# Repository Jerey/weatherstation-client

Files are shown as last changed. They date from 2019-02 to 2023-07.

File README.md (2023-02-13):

# Weatherstation - Client

## Idea

The idea was to create a platform tracking various climate data, which can be extended and has no dependencies to the visualization. Therefore a network based solution was chosen.
<sup>[1](#EnergyConsumption)</sup>

As basis for the project a D1-mini was chosen, as it comes with onboard WiFi. But also other platforms can be used (e.g.: NodeMCU, ...).

The idea is to read the sensor data and send it via MQTT. Anyone who wants to use the data, can simply subscribe to the topic `/esp/#`. To indicate the type of data, the messages are defined by a MAC (to know from which client the message comes from), the type of data and the value. In this case, the topic holds this information in following structure: `/esp/MAC_ADDRESS/TYPE_OF_DATA/`

Have a look at [Weatherstation Server](https://github.com/jerey/weatherstation-server).

## Current State

Currently, two parameters are published:

1. Temperature
2. Humidity

Further can be added by using a different or further sensor.

## Visualization of Data

How the data is visualized is pretty much up to the user. Either one can use another D1-mini with an attached display, or one can use a server, which collects the data and visualizes it in a browser.

## Setup

The setup is split up into two areas: hardware setup and software setup.

### Hardware

The list of needed hardware is as follows:

- D1 Mini or an ESP 01
- BME 280
- 2 x 4k7 Ohm Resistor
- Button

#### D1 Mini setup

Following is the schematic for this setup with an **D1 Mini**.



Note: The BME280 was added with wires to get a more precise temperature. Initially it was also added to the base shield, but there the temperature was always a bit higher.

#### ESP 01 setup

If you want to reduce power consumption even more, you can use the **ESP01**.

Following pins from the [D1 mini](#d1-mini-setup) have to be changed then:

- `D3` :arrow_right: `Pin 0`
- `D4` :arrow_right: `Pin 2`

Further, to enable deep sleep, a little soldering has to be done. There are several tutorials in the internet for that, so I will not go into that here.

### Software

As basis for the software, platform IO was used as it comes with a good library management and makes flashing rather easy. But first have a look into the code.

#### Software settings

The software allows several settings within the `program.cpp`. There are more than the mentioned ones, but those are the most important ones:

1. `BME280_I2C_ADDR` - Depending on the used BME280, there are different I^2^C addresses in use. The used library offers a way to set this address, as described [here](https://github.com/adafruit/Adafruit_BME280_Library/issues/15). Usually the address is either `0x76` or `0x77`. Please check the datasheet of the used BME280 and set the value.
2. `ssidAP` & `passwordAP` - The SSID and password of the accesspoint, which the hardware starts, in case it cannot connect to any wifi. One can then look for the wifi `ssidAP` and connect to it with the password `passwordAP`.
3. `updateFrequency` - The frequency of updates of the parameters/values to be sent to the network. Defined in milliseconds.

#### Flashing

Install platformIO as described on their [webpage](https://docs.platformio.org/en/latest/core.html).
If you chose platformIO for the CLI, you can execute following command from the terminal: `platformio run --target upload`
If you use an ide, please refer to the [platformIO documenation](https://docs.platformio.org/en/latest/ide/pioide.html).

## Documentation

This chapter aims to describe some essential parts of the software.

## Usage of the client

When the software is flashed, the client will directly start. If it has not been configured previously, it will open up an accesspoint. Otherwise it will simply reconnect to the last configured WiFi and start publishing the data.

### Accesspoint at the beginning

When the client is started, the [WiFiManager](https://github.com/tzapu/WiFiManager) is being used to check, whether it has any known WiFi available to connect to. If it either does not know any WiFi or cannot connect to one, it opens up an access point and provides an user interface to setup the desired WiFi. From that point on, it will always try to connect to that WiFi. If you want to connect to another WiFi, press the button added to the board and the access point will again be opened.

### Flashing software to several clients

Work in progress: It currently is possible to flash several clients at once. The [ESP8266httpUpdate](https://github.com/esp8266/Arduino/tree/master/libraries/ESP8266httpUpdate) library is used to auto update the firmware, if the defined update server provides any new firmware. This decision is based on a version defined in the `program.cpp`. For now a python flask server is used as update server. This is currently based on the docker image [esp-update-server](https://hub.docker.com/r/kstobbe/esp-update-server/). For more information on that, checkout the [readme.md](https://github.com/kstobbe/esp-update-server).

## Some Images

On a breadboard:

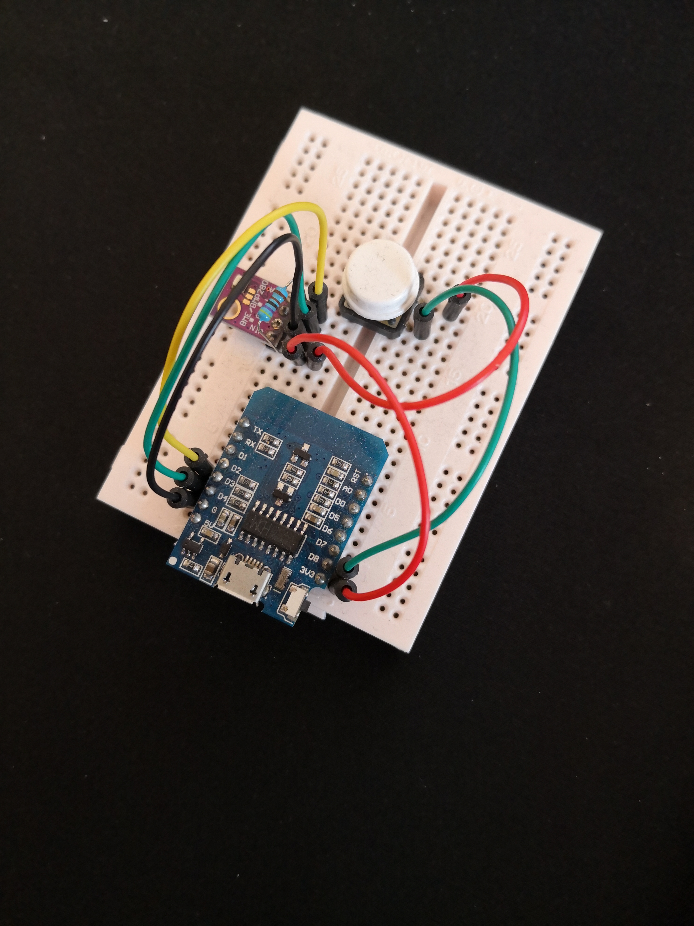
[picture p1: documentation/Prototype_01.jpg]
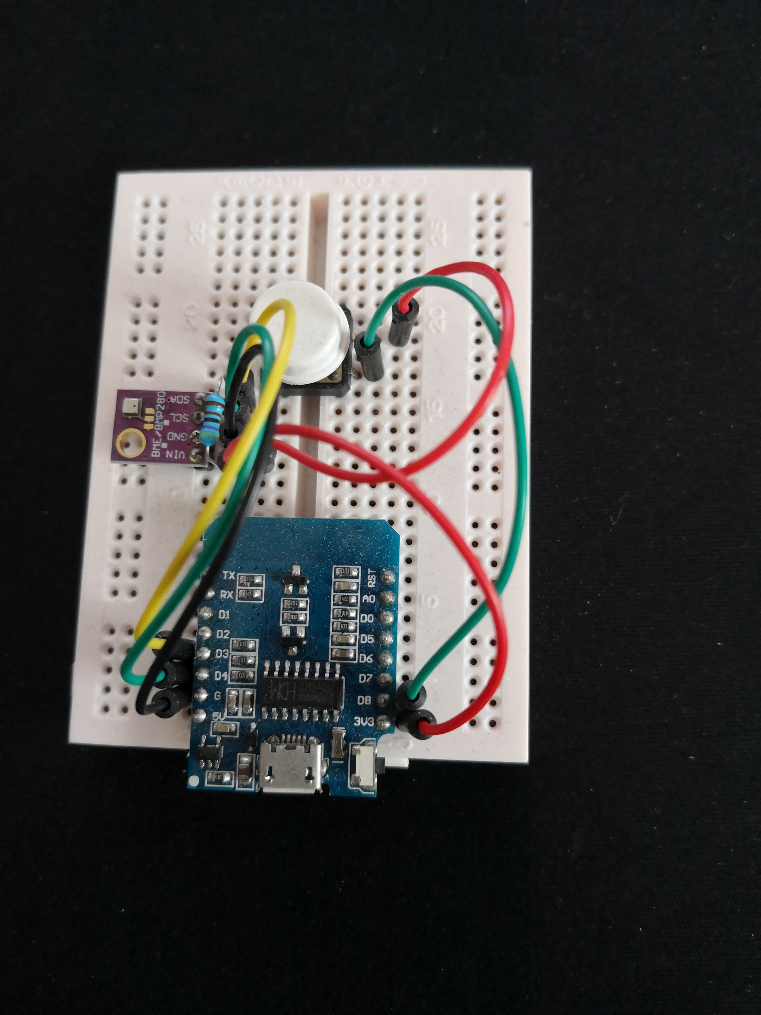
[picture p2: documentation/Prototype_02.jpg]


Further, one can also buy base shields and then solder all parts together:

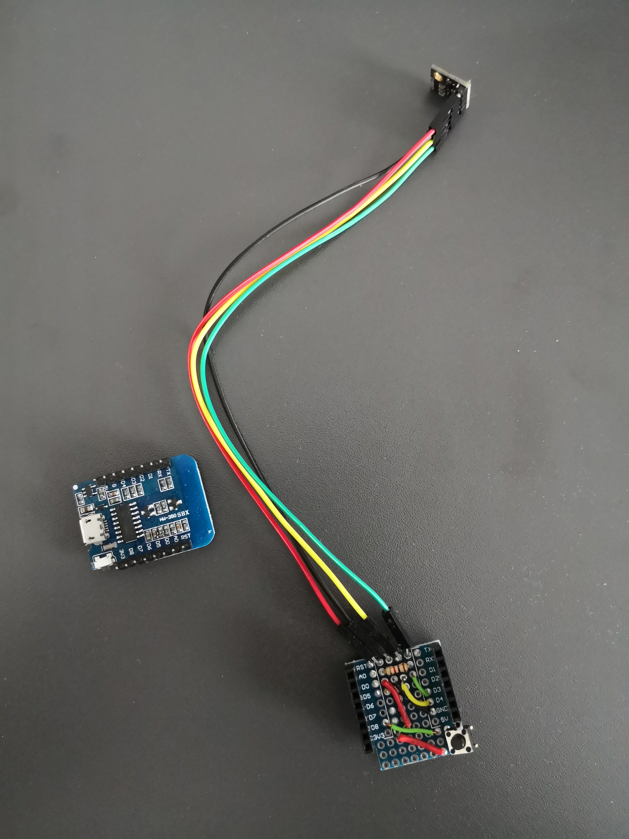
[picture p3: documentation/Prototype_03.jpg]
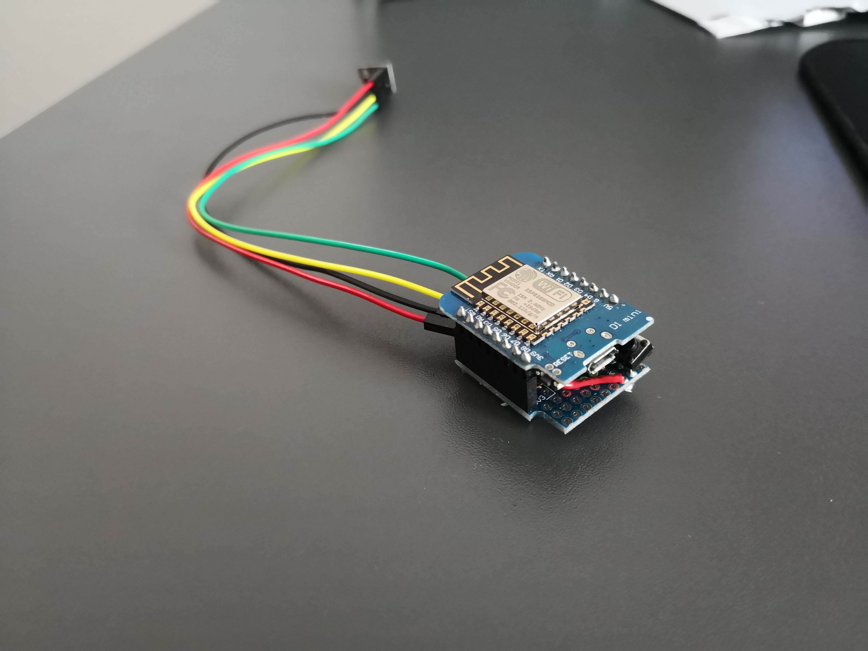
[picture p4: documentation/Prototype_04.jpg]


## Footnotes

<a name="EnergyConsumption">1</a>: For the purpose of the project, the network based solution is fine, but if one wants to tweak the energy consumption to a minimum, other options should be considered (e.g.: Bluetooth Low Energy (BLE), ...).

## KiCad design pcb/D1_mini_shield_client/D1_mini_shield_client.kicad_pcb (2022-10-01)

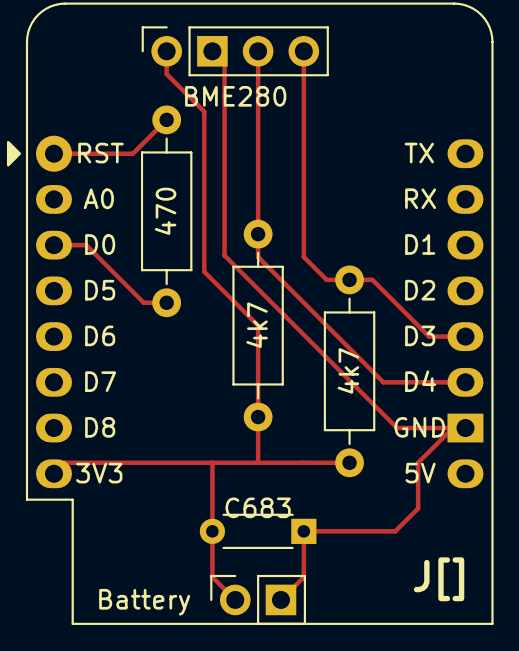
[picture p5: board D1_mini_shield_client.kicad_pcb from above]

Board: 2 copper layers, 7 parts (0 on the bottom side), 6 nets.

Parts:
C683: C; R_Axial_DIN0204_L3.6mm_D1.6mm_P5.08mm_Horizontal
J1: BME280; PinSocket_1x04_P2.54mm_Vertical
J2: Battery; PinSocket_1x02_P2.54mm_Vertical
R1, R3: 4k7; R_Axial_DIN0207_L6.3mm_D2.5mm_P10.16mm_Horizontal
R2: 470; R_Axial_DIN0207_L6.3mm_D2.5mm_P10.16mm_Horizontal
U1: WeMos_mini; WEMOS_D1_mini_light_correctpins

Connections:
/3V3: C683.2, J1.1, J2.1, R1.1, R3.1, U1.16
/D0: R2.1, U1.11
/D3: J1.4, R1.2, U1.4
/D4: J1.3, R3.2, U1.3
/GND: C683.1, J1.2, J2.2, U1.2
/RST: R2.2, U1.9

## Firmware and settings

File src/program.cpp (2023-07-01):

#include <Adafruit_BME280.h>
#include <Arduino.h>
#include <PubSubClient.h>
#include <WiFiManager.h>
#include <string>

//----------- Non Blocking Refresh Parameters -----------
constexpr unsigned long updateFrequency = 15 * 60 * 1000;  // In ms.

//----------- CONSTANTS -----------
// usually 0x76 or 0x77 --> See
// https://github.com/adafruit/Adafruit_BME280_Library/issues/15
constexpr uint8_t BME280_I2C_ADDR = 0x76;

//----------- BME Sensure Setup -----------
Adafruit_BME280 bme;

//----------- AP -----------
constexpr const char *ssidAP = "AutoConnectAP";
constexpr const char *passwordAP = "password";
constexpr unsigned long configPortalTimeout = 600;

//----------- MAC Address -----------
std::string macAddress;
std::string topic;

//----------- MQTT -----------
constexpr const char *mqttBroker =
    "192.168.178.100";  // Enter your mqtt broker address here.
WiFiClient espClient;
PubSubClient mqttClient(espClient);
char mqttBuffer[64];

//----------- MQTT Topics -----------
constexpr const char *topicTemperature = "/temperature";
constexpr const char *topicHumidity = "/humidity";
constexpr const char *topicVoltage = "/voltage";

/**
 * Function to connect to a wifi. It waits until a connection is established.
 */
void connectToWifi() {
  WiFiManager wifiManager;
  wifiManager.setBreakAfterConfig(true);

  // If nobody has configured the wifi in the given timeout ..
  // .. restart the ESP and try to reconnect to the previous WiFi.
  wifiManager.setConfigPortalTimeout(configPortalTimeout);
  wifiManager.setConfigPortalTimeoutCallback([] { ESP.restart(); });

  wifiManager.autoConnect(ssidAP, passwordAP);

  Serial.println(WiFi.SSID());
  auto mac = std::string(WiFi.macAddress().c_str());
  mac.erase(std::remove(mac.begin(), mac.end(), ':'), mac.end());
  macAddress = mac;
  topic = "esp/" + macAddress;
  Serial.println(" -> Success!");
}

/**
 * Function to be used, when an error is detected.
 * @param slowblinks Defines how many slow blinks shall occur per execution.
 * @param fastblinks Defines how many fast blinks shall occur per execution.
 * @param loop [false] Execute the blinking and logging routine once. [true]
 * Execute the blinking and logging routine endless.
 * @param logMessage The log message, which shall be print to the serial
 * console.
 */
void errorDetected(uint8_t slowblinks, uint8_t fastblinks, bool loop,
                   const char *logMessage) {
  pinMode(LED_BUILTIN, OUTPUT);
  do {
    Serial.println(logMessage);
    for (unsigned int i = 0; i < slowblinks; ++i) {
      digitalWrite(LED_BUILTIN, LOW);
      delay(250);
      digitalWrite(LED_BUILTIN, HIGH);
      delay(250);
    }
    for (unsigned int i = 0; i < fastblinks; ++i) {
      digitalWrite(LED_BUILTIN, LOW);
      delay(100);
      digitalWrite(LED_BUILTIN, HIGH);
      delay(100);
    }
  } while (loop);
}

//----------- Setup -----------
ADC_MODE(ADC_VCC)
void setup() {
  Serial.begin(115200);
  Serial.println(
      "**************************\n\r******** BEGIN "
      "***********\n\r**************************");
#ifdef ESP01
  Wire.begin(0, 2);
  pinMode(16, WAKEUP_PULLUP);
#endif
#ifdef D1MINI
  Wire.begin(D3, D4);
  pinMode(D0, WAKEUP_PULLUP);
#endif
  Wire.setClock(100000);
  bool status = bme.begin(BME280_I2C_ADDR);
  if (!status) {
    errorDetected(4, 4, false,
                  "Could not find a valid BME280 sensor, check wiring or if "
                  "the defined I2C address is correct!");
  }
  connectToWifi();
  Serial.print("Mqtt broker address given: ");
  Serial.println(mqttBroker);
  mqttClient.setServer(mqttBroker, 1883);
}

/**
 * Tries to reconnect to the mqtt broker.
 */
void reconnectToMqttBroker() {
  while (not mqttClient.connected()) {
    Serial.print("Reconnecting...");
    if (not mqttClient.connect("ESP8266Client")) {
      Serial.print("failed, rc=");
      Serial.print(mqttClient.state());
      Serial.println(" retrying in 5 seconds");
      delay(5000);
    }
  }
}

/**
 * @brief Tries to publish the given sensorValue to the given targetTopic
 */
void publishMqttTopic(float sensorValue, const char *targetTopic) {
  snprintf(mqttBuffer, sizeof mqttBuffer, "%f", sensorValue);
  Serial.print(topic.c_str());
  Serial.print(targetTopic);
  Serial.print(": ");
  Serial.println(sensorValue);
  auto resultOfPublish =
      mqttClient.publish((topic + targetTopic).c_str(), mqttBuffer);
  if (not resultOfPublish) {
    const char *errorLog =
        (std::string("Failed publishing topic: '") + targetTopic).c_str();
    errorDetected(3, 3, false, errorLog);
    Serial.print("State of client: ");
    Serial.println(mqttClient.state());
  }
  mqttClient.loop();
}
/**
 * Function to handle sensor updates.
 */
void handleSensorUpdates() {
  reconnectToMqttBroker();

  mqttClient.loop();
  publishMqttTopic(bme.readTemperature(), topicTemperature);
  publishMqttTopic(bme.readHumidity(), topicHumidity);
  publishMqttTopic(ESP.getVcc() / 1024.0f, topicVoltage);
}

//----------- LOOP -----------
void loop() {
  handleSensorUpdates();
  mqttClient.disconnect();
  ESP.deepSleep(updateFrequency * 1000);
}

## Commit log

2019-06-21 Replace handdrawn schematic.
2019-10-01 Add missing resistor for the schematic.
2019-10-03 Remove the messages
    The messages are now no longer needed. This is handled via MQTT now.
    Therefore the messages are deleted, their tests are no longer required and since the program.cpp currently is not tested, travis is for now also remove.
2019-11-09 DeepSleep and remove wifi config button
    - Deep sleep has now been activated.
    - The wifi configuration button has been removed.
2019-12-30 Disconnect after publishing new sensor data.
    Reconnection errors to the MQTT broker can occur if the client simply disconnects due to deep sleep.
    Therefore disconnecting from the broker properly is essential.
    [program.cpp]
2020-01-02 Measure the current voltage and publish.
2021-01-06 Add first pcb prototype.
    [D1_mini_shield_client.kicad_pcb, D1_mini_shield_client.sch]
2022-10-01 Update pcb.
    [D1_mini_shield_client.kicad_pcb, D1_mini_shield_client.kicad_sch]
